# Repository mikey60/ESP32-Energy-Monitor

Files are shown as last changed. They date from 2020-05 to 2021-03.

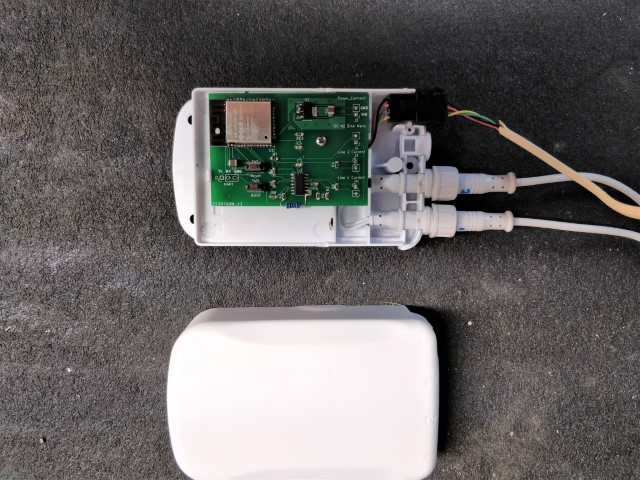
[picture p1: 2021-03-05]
Images/Energy_monitor_1 (Small).jpg

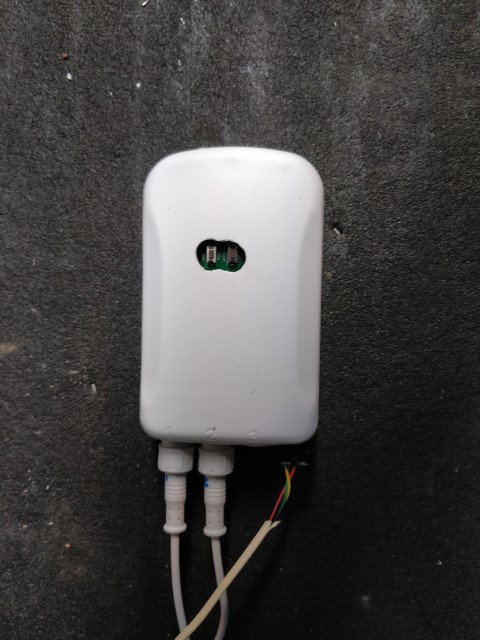
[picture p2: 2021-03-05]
Images/Energy_monitor_2 (Small).jpg

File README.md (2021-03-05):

# ESP32-Energy-Monitor
Hardware and code are designed to use the Aeon labs Home Energy Meter, model DSB09104-zwus, current clamps and housing.  I was frustrated with the occasional intermittent connection of the Aeon Labs Home Energy meter because the Z-Wave hub and energy meter were two floors apart.  Also the energy meter would occasionally give very high erroneous readings.  The unit did not work at all after I upgraded the firmware. That is what led to the ESP32 energy monitor project.

**Features:**
* Uses Aeon labs DSB09104-zwus current clamps and housing
* Wifi has increased signal strength over Z-Wave
* Uses a minimum amount of components
* Calculates real power like residential energy meters
* The capability of calculating power factor could be added
* Can easily adjust the scale factors to get agreement with energy company's meter
* Can debug using WiFi and telnet
* Can download new code Over The Air (OTA)

**Disadvantages:**
* The power supply is old school with a 60Hz transformer with a diode bridge and 1000uF capacitor to provide the DC power and the 60 Hz AC signal to the energy meter.  I picked up the 6 volt DC, 800mA class 2 power supply at the local surplus store.  I opened the power supply to add the two wires for the sine wave input to the energy monitor.  I also added two 1 amp rectifier diodes in series with the filtered DC output to the reduce the power of the AMS1117-3.3 LDO regulator on the energy monitor board.
* There is some distortion of the sine wave voltage due to the load on the power supply.
* The output of the current clamps is also distorted especially at low currents. The linearity of the output versus power is not too bad even with the distortion.
* The WiFi activity adds some noise to  the A/D coversions.
* The energy totals get reset if there is a wifi problem or power interruption. Additonal code could be written to keep a running sum in Flash every so often.

**PCB**

The KiCad PCB files can be found in the PCB folder including a PDF file of the schematic and layout.
There are two modifications that I made to the hardware design that are not shown in the documentation of the PCB folder.

Modifications
* I added a 22uF capacitor directly across the output and ground pins of the AMS1117-3.3 LDO regulator to stop the output oscillation.  The other 22uF capacitor on the 3.3 volt output of the LDO regulator is close to the ESP32. 
* I addded a 200pF capacitor and a 100 ohm resistor to the op amp circuit that provides the 3.3/2 volt virtual ground to provide stability when driving a capacitive load.  The output would oscillate when a 1x probe (120pF capacitance) was touched to the output.  The Micro-Cap 12 stability analysis showed that the circuit should be stable with a 120pF capacitor.  See 'Stability Analysis' in the data folder. Maybe there is other capacitances I am not accounting for or maybe the LMC6484 op amp I purchased on ebay is deficient in the stability performance area.  The Micro-Cap file is also in the data folder.  By the way, the Micro-cap 12 simulator is now free. 

**Other Information**

* Pictures of the finished device can be found in the images folder.
* A plot of the current consumption of the device can be found in the data folder.
* I attached a logic analyzer  to pin IO4 and let it run for an hour and did not see any missed 1 KHz samples

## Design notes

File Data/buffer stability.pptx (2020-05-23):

## LM6484 Stability Analysis

120pf 1X scope probe load

## Virtual Ground Amplifier Stability as Designed

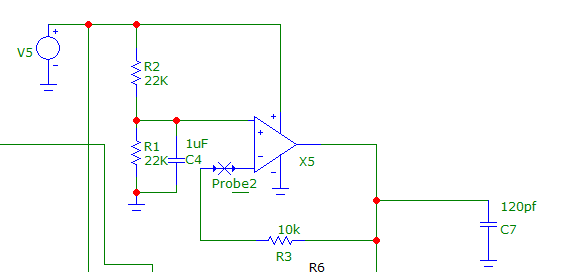
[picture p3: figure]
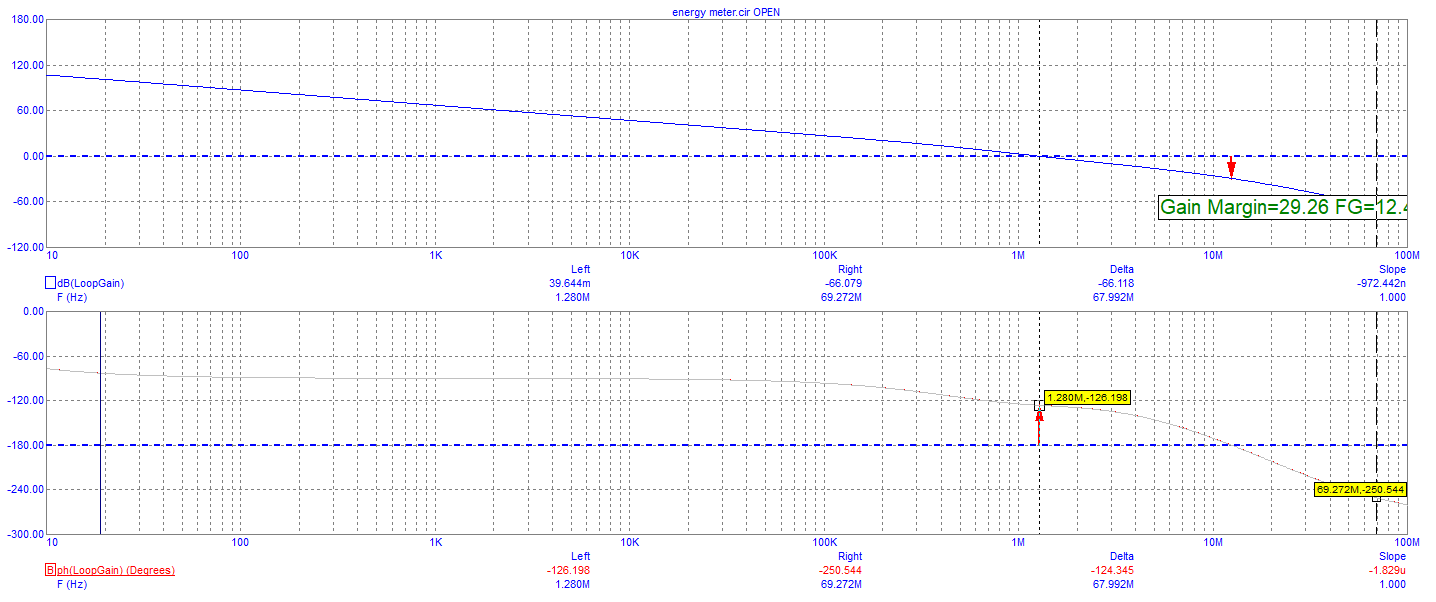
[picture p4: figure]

Phase Margin = 53.78°

## Virtual Ground Amplifier Stability with Capacitive Load Capability

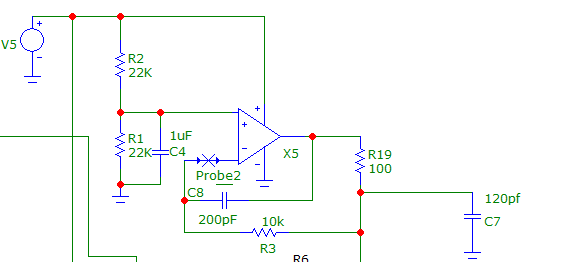
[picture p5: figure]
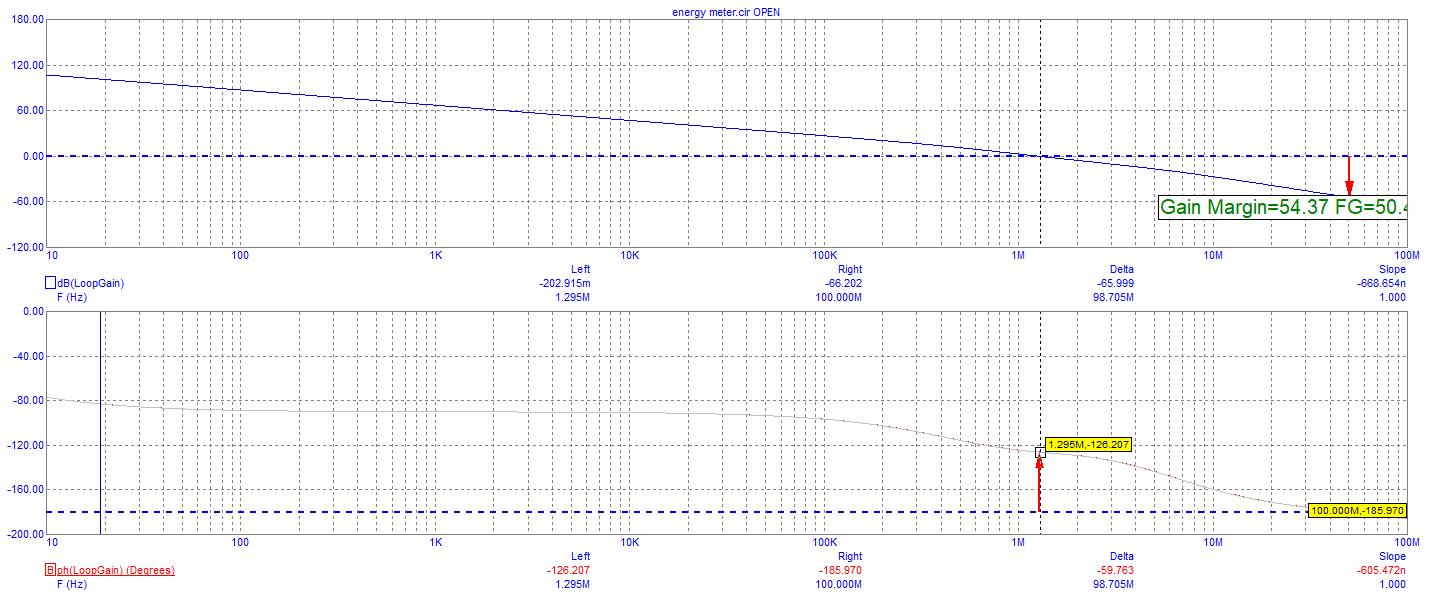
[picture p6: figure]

Phase Margin = 53.9°

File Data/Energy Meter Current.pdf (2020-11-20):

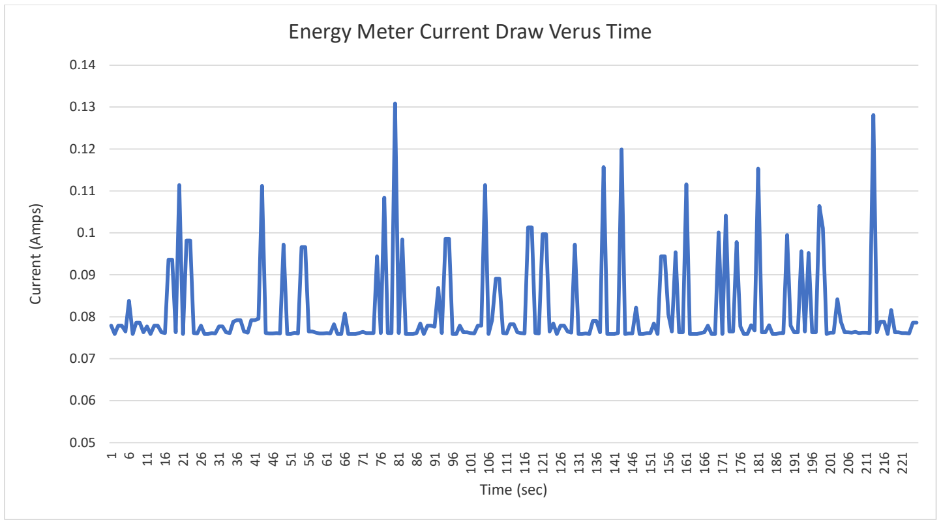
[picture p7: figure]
Time (sec); Energy Meter Current Draw Verus Time

6111621263136414651566166717681869196 101 106 111 116 121 126 131 136 141 146 151 156 161 166 171 176 181 186 191 196 201 206 211 216 221 Current (Amps)

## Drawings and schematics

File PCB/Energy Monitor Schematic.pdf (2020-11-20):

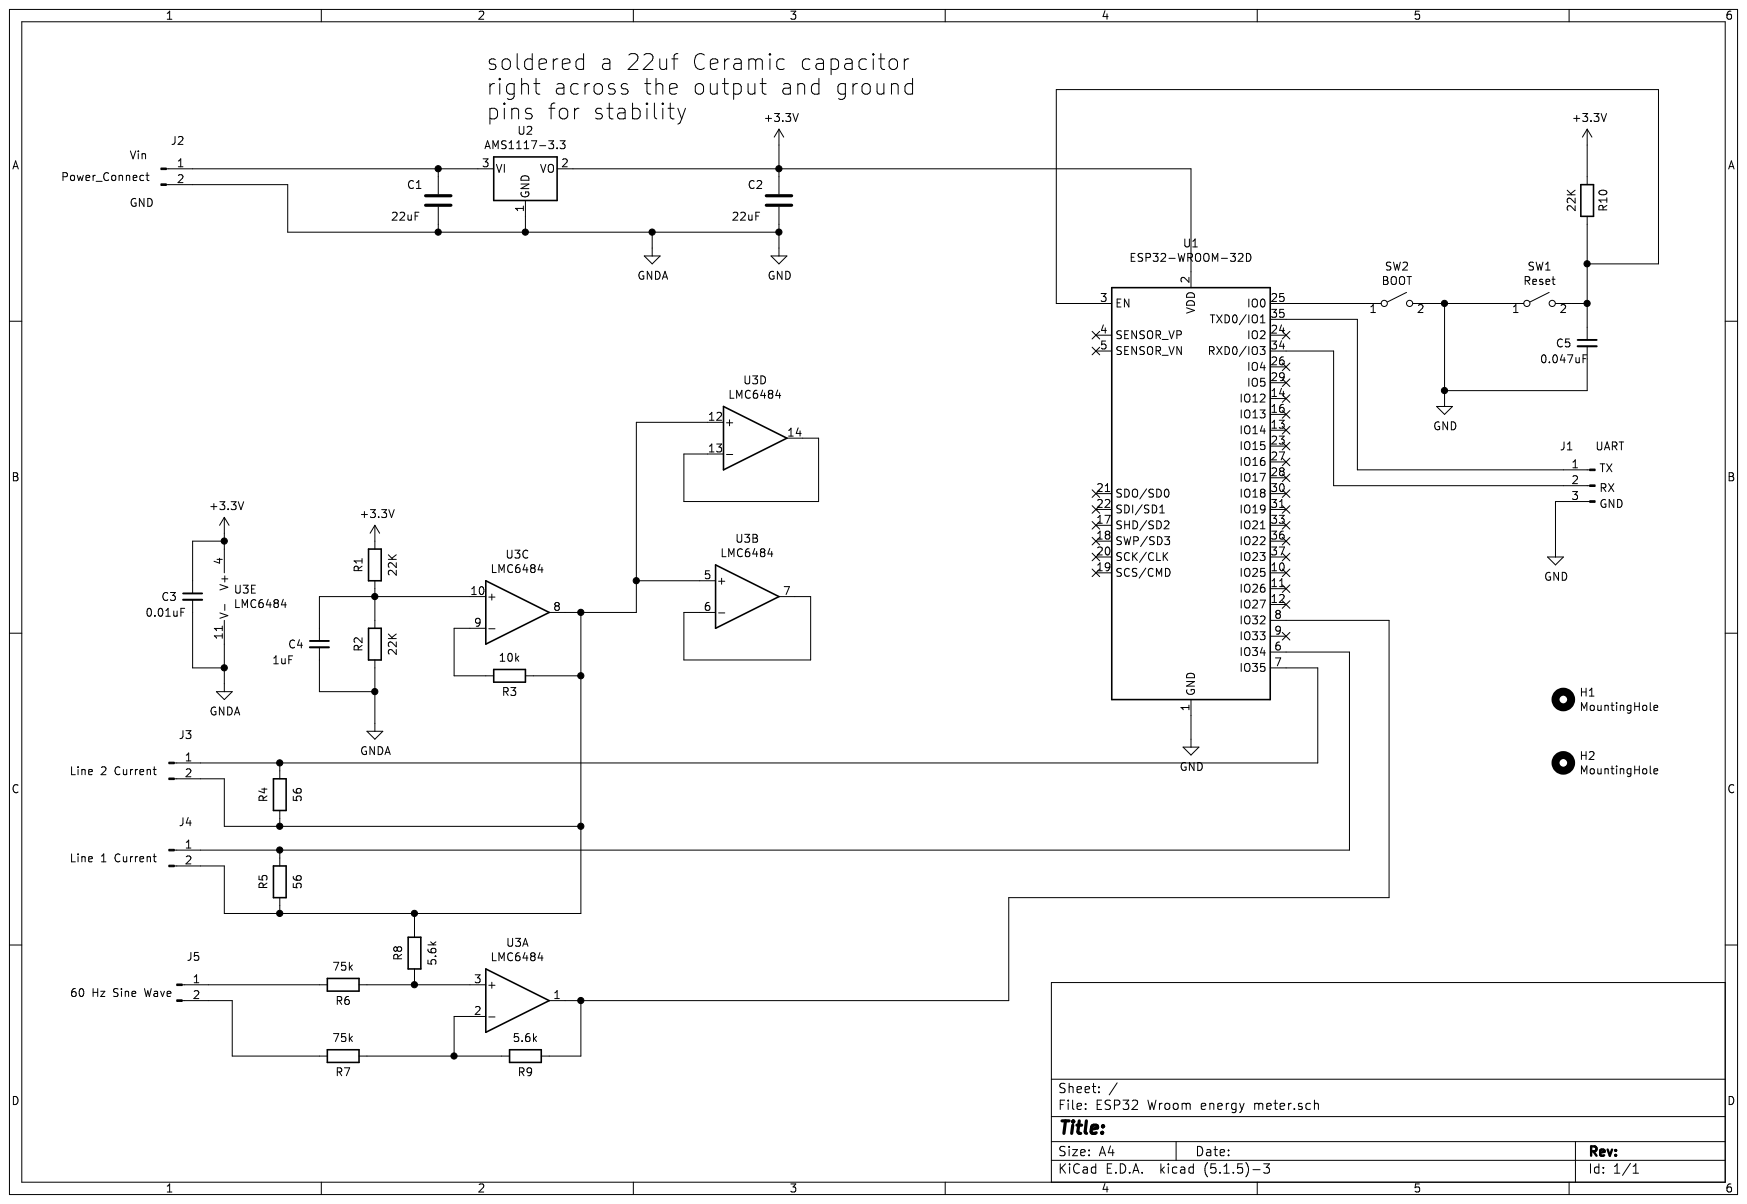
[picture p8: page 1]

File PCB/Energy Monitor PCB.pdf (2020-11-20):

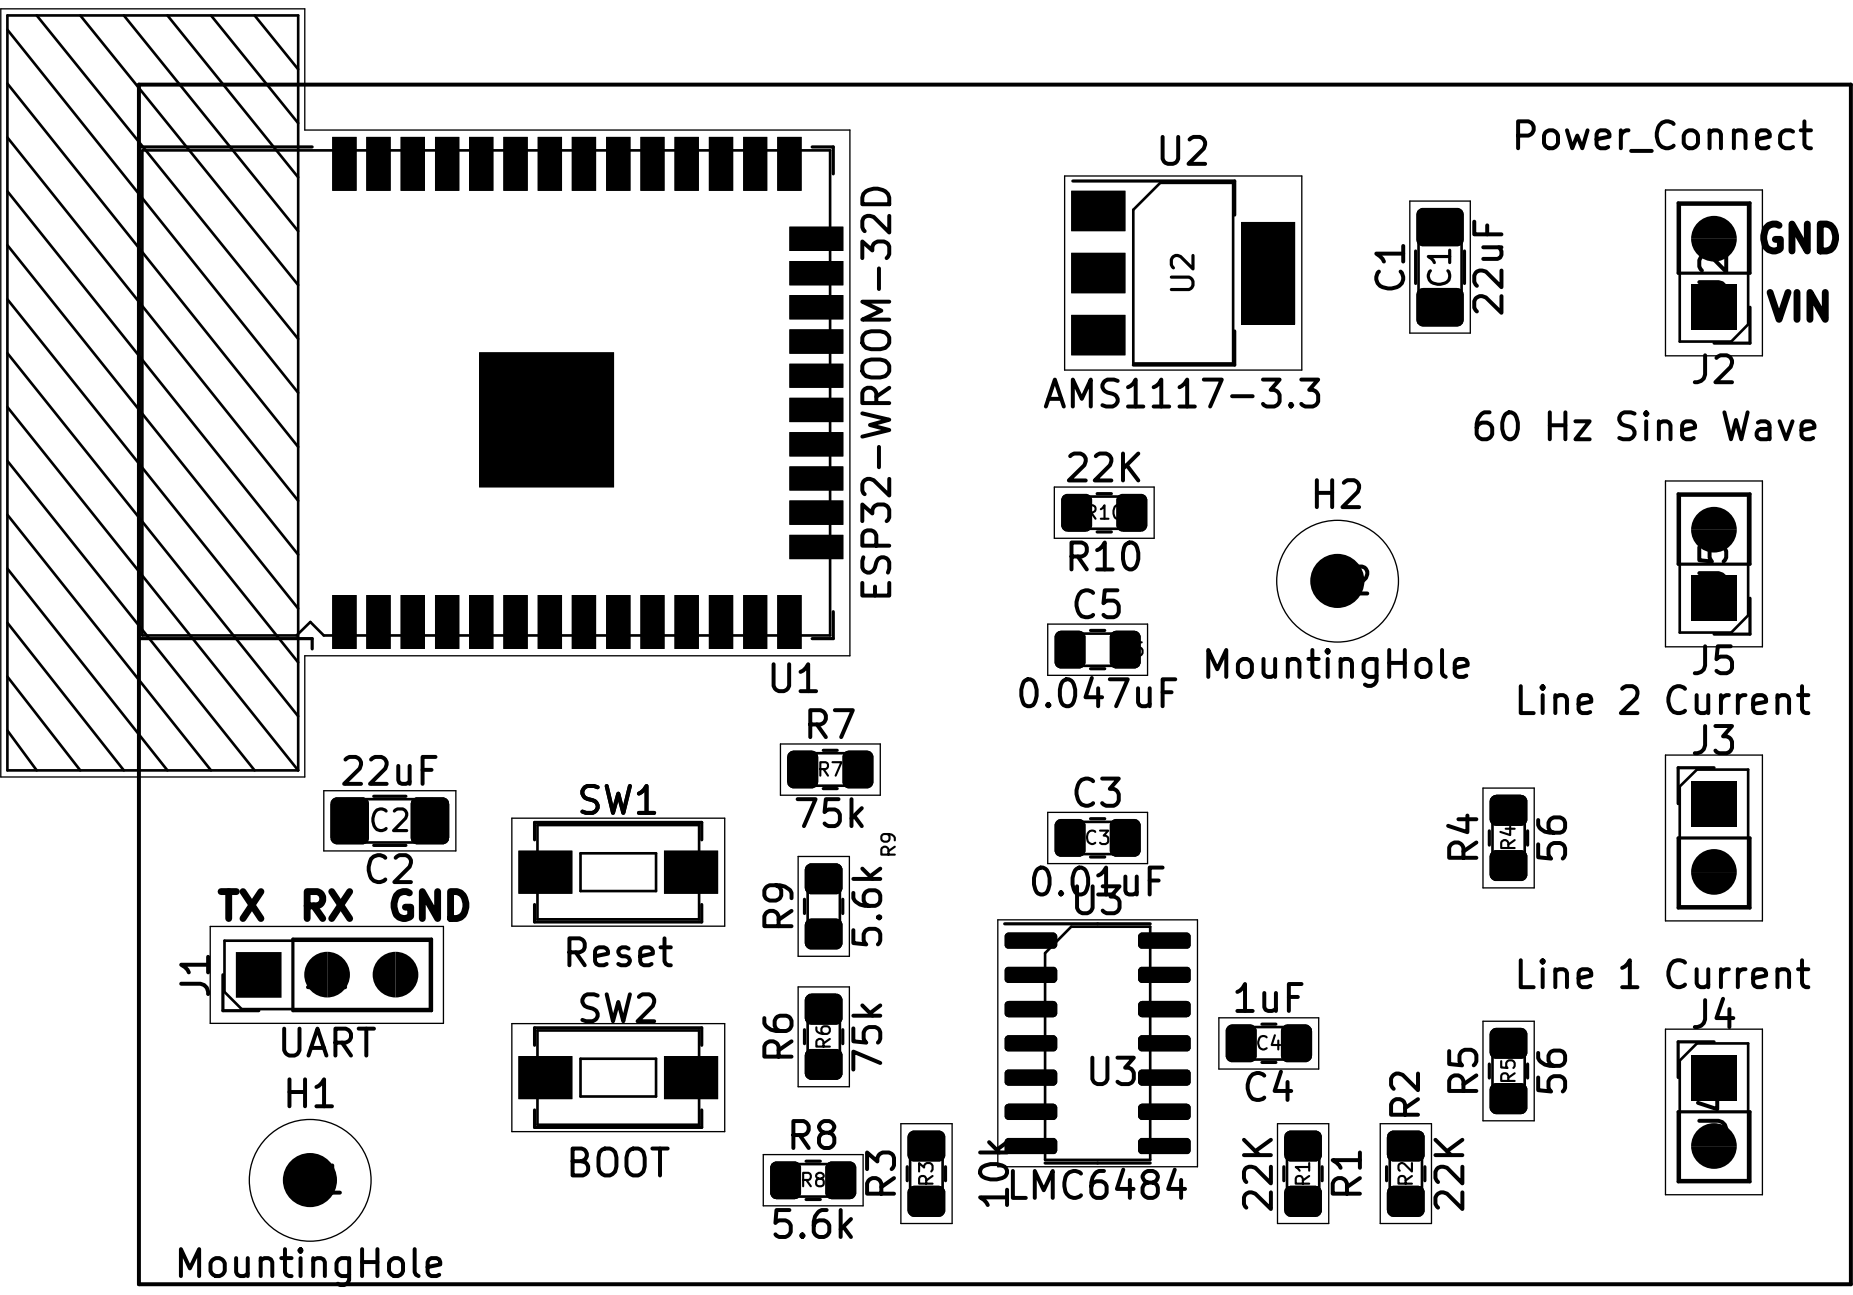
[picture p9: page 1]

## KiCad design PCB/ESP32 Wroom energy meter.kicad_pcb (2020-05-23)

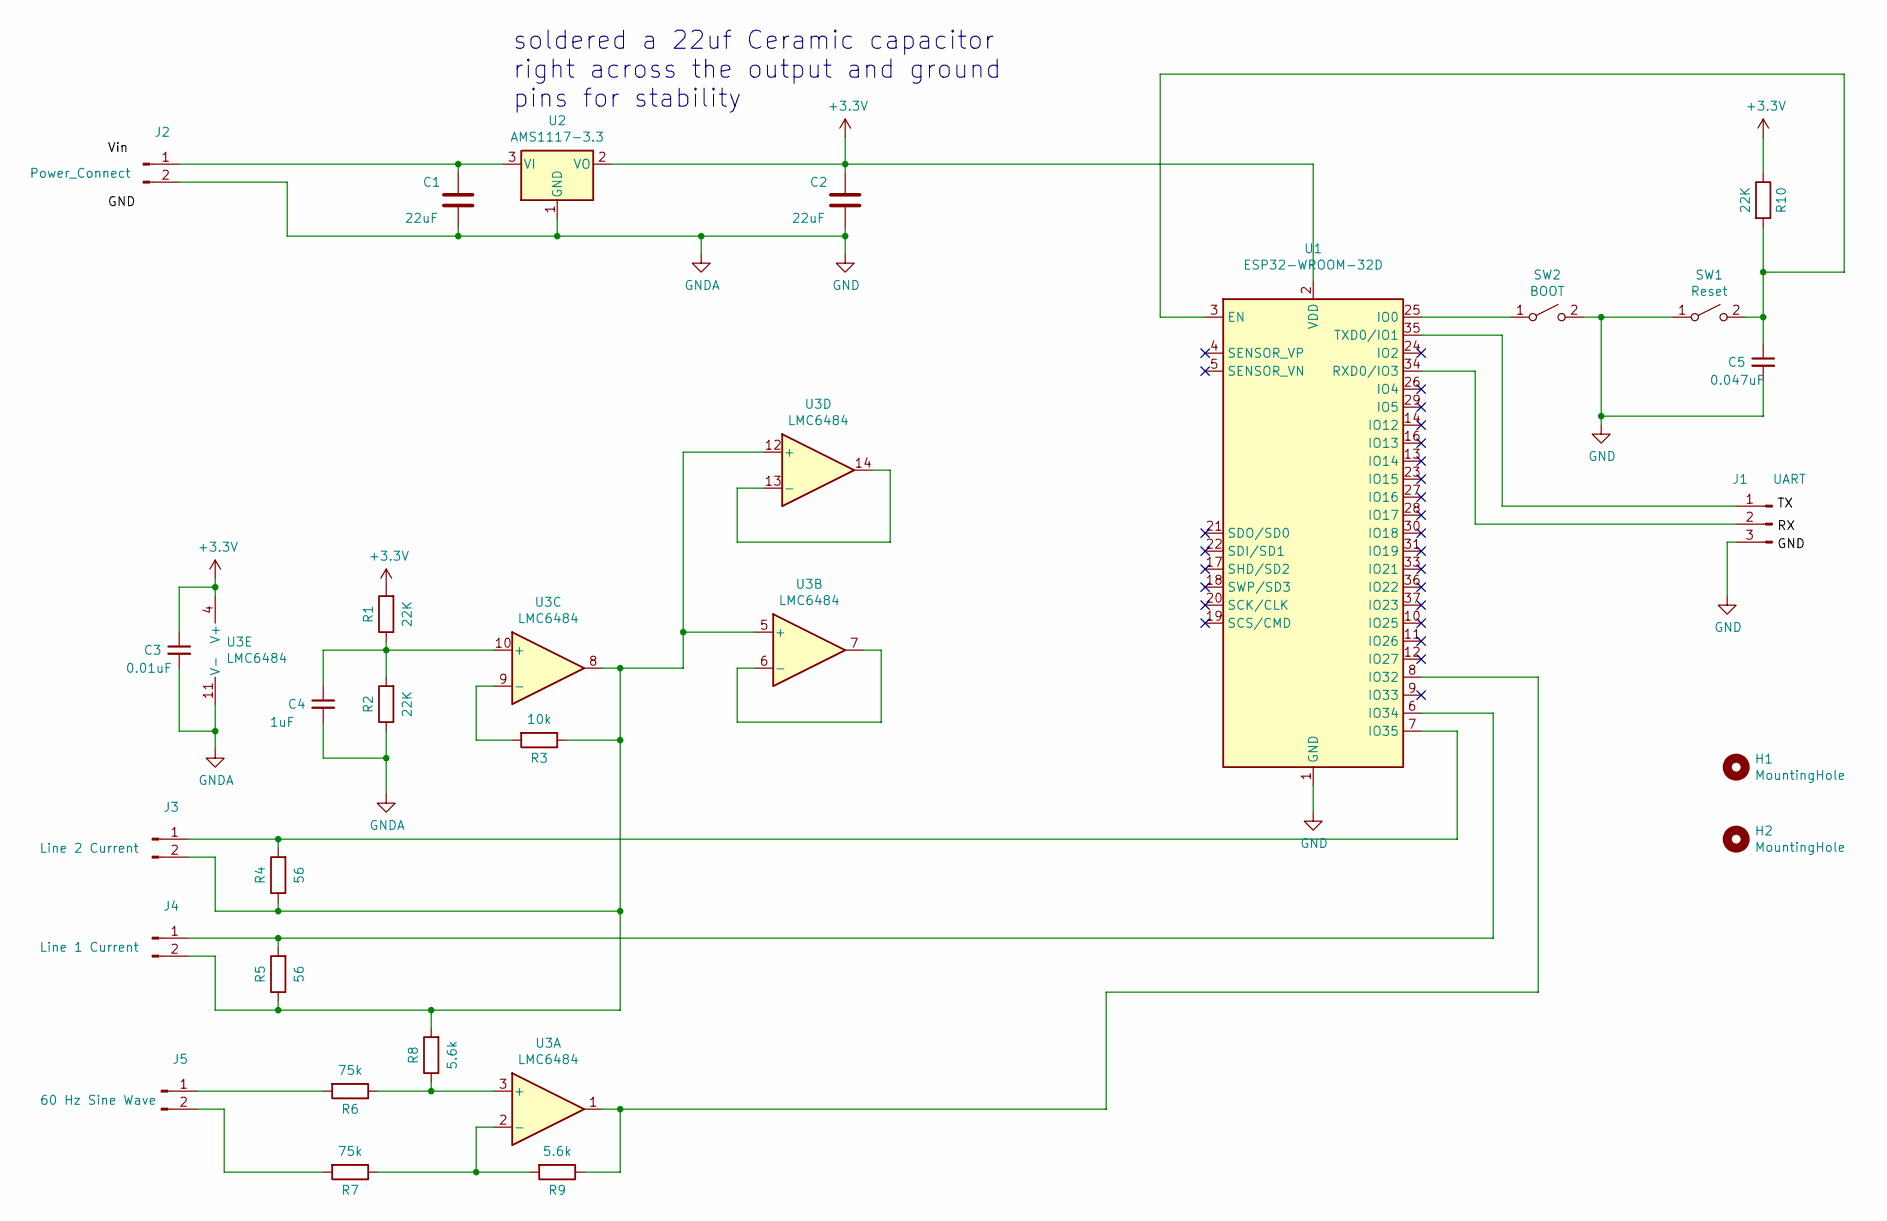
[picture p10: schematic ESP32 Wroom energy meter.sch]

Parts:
C1, C2: 22uF; C_1206_3216Metric_Pad1.42x1.75mm_HandSolder
C3: 0.01uF; C_0805_2012Metric_Pad1.15x1.40mm_HandSolder
C4: 1uF; C_0805_2012Metric_Pad1.15x1.40mm_HandSolder
C5: 0.047uF; C_0805_2012Metric_Pad1.15x1.40mm_HandSolder
H1, H2: MountingHole; MountingHole_2mm
J1: UART; PinHeader_1x03_P2.54mm_Vertical
J2: Power_Connect; PinHeader_1x02_P2.54mm_Vertical
J3: Line 2 Current; PinHeader_1x02_P2.54mm_Vertical
J4: Line 1 Current; PinHeader_1x02_P2.54mm_Vertical
J5: 60 Hz Sine Wave; PinHeader_1x02_P2.54mm_Vertical
R1, R2, R10: 22K; R_0805_2012Metric_Pad1.15x1.40mm_HandSolder
R3: 10k; R_0805_2012Metric_Pad1.15x1.40mm_HandSolder
R4, R5: 56; R_0805_2012Metric_Pad1.15x1.40mm_HandSolder
R6, R7: 75k; R_0805_2012Metric_Pad1.15x1.40mm_HandSolder
R8, R9: 5.6k; R_0805_2012Metric_Pad1.15x1.40mm_HandSolder
SW1: Reset; SW_SPST_EVQPE1
SW2: BOOT; SW_SPST_EVQPE1
U1: ESP32-WROOM-32D; ESP32-WROOM-32
U2: AMS1117-3.3; SOT-223-3_TabPin2
U3: LMC6484; SOIC-14_3.9x8.7mm_P1.27mm

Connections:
+3V3: C2.1, C3.1, R1.2, R10.1, U1.2 (VDD), U2.2 (VO), U3.4 (V+)
GND: C1.2, C2.2, C3.2, C4.2, C5.2, J1.3, J2.2, R2.1, SW1.1 (A), SW2.2 (B), U1.1 (GND), U1.15 (GND), U1.38 (GND), U1.39 (GND), U2.1 (GND), U3.11 (V-)
unnamed: C1.1, J2.1, U2.3 (VI)
unnamed: C4.1, R1.1, R2.2, U3.10 (+)
unnamed: C5.1, R10.2, SW1.2 (B), U1.3 (EN)
unnamed: J1.1, U1.35 (TXD0/IO1)
unnamed: J1.2, U1.34 (RXD0/IO3)
unnamed: J3.1, R4.2, U1.7 (IO35)
unnamed: J3.2, J4.2, R3.1, R4.1, R5.1, R8.2, U3.5 (+), U3.8, U3.12 (+)
unnamed: J4.1, R5.2, U1.6 (IO34)
unnamed: J5.1, R6.2
unnamed: J5.2, R7.2
unnamed: R3.2, U3.9 (-)
unnamed: R6.1, R8.1, U3.3 (+)
unnamed: R7.1, R9.2, U3.2 (-)
unnamed: R9.1, U1.8 (IO32), U3.1
unnamed: SW2.1 (A), U1.25 (IO0)
unnamed: U3.6 (-), U3.7
unnamed: U3.13 (-), U3.14

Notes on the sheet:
soldered a 22uf Ceramic capacitor right across the output and ground pins for stability

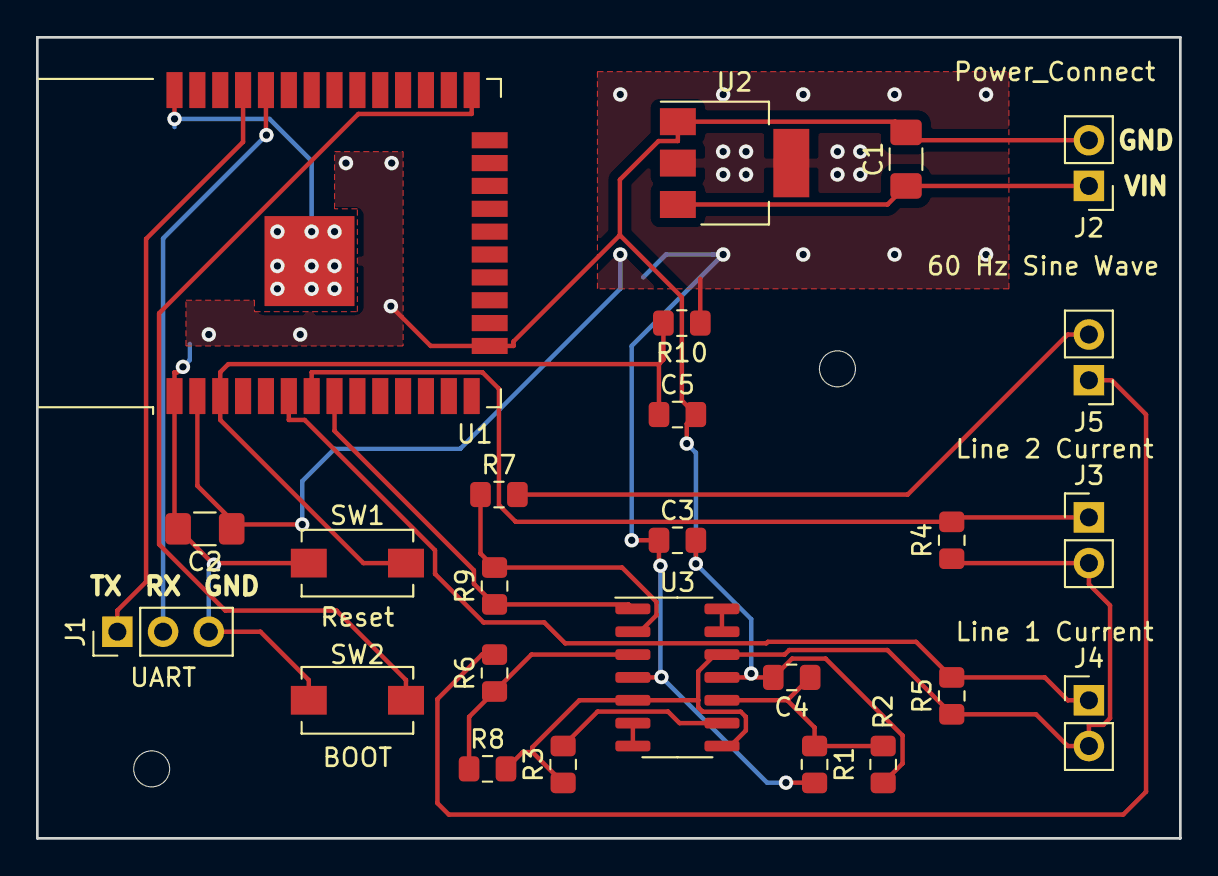
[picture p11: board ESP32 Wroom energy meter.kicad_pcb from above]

Board: 2 copper layers, 63.5 x 44.5 mm, 27 parts (0 on the bottom side), 19 nets.

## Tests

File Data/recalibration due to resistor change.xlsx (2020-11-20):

Meter reading | Delta | ESP32 reading | Delta | Ratio
2352.5 |  | 0.19
2413.5 | 61 | 66.03 | 65.84 | 0.9264884569
2677 | 263.5 | 350.85 | 284.82 | 0.9251457061
2744.7 | 67.7 | 424.04 | 73.19 | 0.9249897527
 |  |  |  | 0.9255413052 | = average correction factor

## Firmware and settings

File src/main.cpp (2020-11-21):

/***************************************************************************
 MQTT Energy Monitor uses Aeon labs DSB09104-zwus current clamps and housing 
****************************************************************************/ 
#include <WiFi.h>
#include <PubSubClient.h>
#include <ArduinoOTA.h>
#include "esp_wifi.h"

//#define DEBUG_SERIAL
#define DEBUG_TELNET

#if defined(DEBUG_TELNET)
#define DEBUG_TELNET_PORT 23
#endif

#if defined(DEBUG_TELNET)
WiFiServer  telnetServer(DEBUG_TELNET_PORT);
WiFiClient  telnetClient;
#define     DEBUG_PRINT(x)    telnetClient.print(x)
#define     DEBUG_PRINTLN(x)  telnetClient.println(x)

#elif defined(DEBUG_SERIAL)
#define     DEBUG_PRINT(x)    Serial.print(x)
#define     DEBUG_PRINTLN(x)  Serial.println(x)
#else
#define     DEBUG_PRINT(x)
#define     DEBUG_PRINTLN(x)
#endif

#if CONFIG_FREERTOS_UNICORE
#define ARDUINO_RUNNING_CORE 0
#else
#define ARDUINO_RUNNING_CORE 1
#endif

#ifndef LED_BUILTIN
#define LED_BUILTIN 13
#endif
#define portTICK_PERIOD_MS 1

#define OTA_password "your_OTA_password"
const char* ssid = "your_SSID";
const char* password = "your_SSID_password";
const char* hostname = "Energy Monitor";
const char* mqttServer = "xxx.xxx.xxx.xxx"; //your IP address
const int mqttPort = 1883;
//const char* mqttUser = "yourMQTTuser";   //Use if desired
//const char* mqttPassword = "yourMQTTpassword";

WiFiClient espClient;
PubSubClient client(espClient);

//counters to limit connection retries
volatile int wifi_cnt = 0;
volatile int mqtt_cnt = 0;


const int line1_current = 34; //pin for line 1 current ADC input
const int line2_current = 35; //pin for line 2 current ADC input
const int voltage = 32;  //pin for voltage ADC input
//const int Pin_DC_bias = 25;  // pin to provide dc bias to AC current ADC samples 
const int Pin_time = 4; // pin to check sampling time
const int nsamples = 1000;
const unsigned long time_between_messages = 300000UL; // Time in msec
const double power_change = 200.0;  //The power change threshold to send MQTT message
const double fsamples = 1000.0;
const double twoPI = 6.2831853;
//const int DC_bias = 127; // 255 is full scale ~3.3 volts not using in design using resitor divider
const double SF_line1 = 0.00934755; //  
const double SF_line2 = 0.00934755; // Scale factors determined by calibrating against power meter
volatile int buff_cnt = 0;
volatile int buff1 = true;  // Buffer indicator: true = buff1 and false = buff2 
volatile double line1_buff1[nsamples];
volatile double line1_buff2[nsamples];
volatile double line2_buff1[nsamples];
volatile double line2_buff2[nsamples];
volatile double v_buff1[nsamples];
volatile double v_buff2[nsamples];
volatile bool buff1_full = false;
volatile bool buff2_full = false;
volatile double line1_energy = 0.0;
volatile double line2_energy = 0.0;
volatile double total_energy = 0.0;
volatile double line1_avg_pwr;
volatile double line2_avg_pwr;
volatile double total_power;
volatile double line1_energy_buff = 0.0;
volatile double line2_energy_buff = 0.0;
volatile double total_energy_buff = 0.0;
volatile double line1_avg_pwr_buff = 0.0;
volatile double line2_avg_pwr_buff = 0.0;
volatile double total_power_buff = 0.0;
volatile double value[6];
volatile bool MQTT_message_flag = false;
volatile long last_time = 0L;
String line1_avg_pwr_topic = "sensor/clamp1_power";
String line2_avg_pwr_topic = "sensor/clamp2_power";
String total_power_topic = "sensor/total_power";
String line1_energy_topic = "sensor/clamp1_energy";
String line2_energy_topic = "sensor/clamp2_energy";
String total_energy_topic = "sensor/total_energy";
String topic0 = "sensor/clamp1_power";
String topic1 = "sensor/clamp2_power";
String topic2 = "sensor/total_power";
String topic3 = "sensor/clamp1_energy";
String topic4 = "sensor/clamp2_energy";
String topic5 = "sensor/total_energy";
TaskHandle_t Sc;
TaskHandle_t Cap;
TaskHandle_t Sp;

long strt = 0L;
// Set Static IP address
IPAddress local_IP(192, 168, 1, 41);
// Set Gateway  and subnet
IPAddress gateway(192, 168, 1, 1);
IPAddress subnet(255, 255, 0, 0);


/***          Function Prototypes        ****/
void handleTelnet(void);
double multiple_adc_read(int pinnum);
void Sample_current( void *pvParameters );
void Calculate_avg_power( void *pvParameters );
void Send_power(void *pvParameters);
void callback(char* topic, byte* payload, unsigned int length);
/*
   Function called to handle Telnet clients
   https://www.youtube.com/watch?v=j9yW10OcahI
*/
#if defined(DEBUG_TELNET)
void handleTelnet(void) {
  if (telnetServer.hasClient()) {
    if (!telnetClient || !telnetClient.connected()) {
      if (telnetClient) {
        telnetClient.stop();
      }
      telnetClient = telnetServer.available();
    } else {
      telnetServer.available().stop();
    }
  }
}
#endif

void callback(char* topic, byte* payload, unsigned int length) {
  Serial.print("Message arrived [");
  Serial.print(topic);
  Serial.print("] ");
  for (int i=0;i<length;i++) {
    Serial.print((char)payload[i]);
  }
  Serial.println();
}


/*--------------------------------------------------*/
/*---------------------- Tasks ---------------------*/
/*--------------------------------------------------*/

void Send_power(void *pvParameters)  // This is a task.
// This is a task to send the power and energy data to Home-Assistant MQTT server when flag is set.
{
  (void) pvParameters;
  String topic;
 for (;;) // A Task that never returns or exits.
  {
    vTaskDelay(1);
    ArduinoOTA.handle();
    #if defined(DEBUG_TELNET)
    // handle the Telnet connection
     handleTelnet();
    #endif
    strt=xTaskGetTickCount();
    if(MQTT_message_flag == true)  //Only send data when true
    {
      mqtt_cnt = 0;    
        while (!client.connected() &&  mqtt_cnt <6)
        { 
      
          DEBUG_PRINTLN("Connecting to MQTT...");
          if (client.connect("ESP32Power")) 
          {
            DEBUG_PRINTLN("connected to MQTT server");
            //DEBUG_PRINTLN("line1_avg_pwr string = " + String(line1_avg_pwr_buff));
            client.subscribe(line1_avg_pwr_topic.c_str());
            client.publish(line1_avg_pwr_topic.c_str(), String(line1_avg_pwr_buff).c_str(), true);
            client.publish(line2_avg_pwr_topic.c_str(), String(line2_avg_pwr_buff).c_str(), true);
            client.publish(total_power_topic.c_str(), String(total_power_buff).c_str(), true);
            client.publish(line1_energy_topic.c_str(), String(line1_energy_buff).c_str(), true);
            client.publish(line2_energy_topic.c_str(), String(line2_energy_buff).c_str(), true);
            client.publish(total_energy_topic.c_str(), String(total_energy_buff).c_str(), true);
            client.subscribe(total_energy_topic.c_str());

          } 
          else 
          {
            DEBUG_PRINT("failed with state ");
            DEBUG_PRINTLN(client.state());
            delay(1000);
            mqtt_cnt ++;  // only allow 6 trys for connection to MQTT server
          }
          if(mqtt_cnt >= 6) esp_restart(); // restart the device at this point
          // Todo: Save line 1, line 2 and total energy other wise they are reset to 0
          // Possibly could just call WiFi.mode(WIFI_OFF) and WiFi.begin(...) 
  
         }
      client.disconnect();
      //WiFi.disconnect();    
      //WiFi.mode(WIFI_OFF);
      MQTT_message_flag = false;  //reset flag
      //DEBUG_PRINTLN(xTaskGetTickCount());
        DEBUG_PRINTLN(ESP.getFreeHeap());
      //DEBUG_PRINTLN("Reset MQTT flag");
      //vTaskResume(Sc);
      //vTaskResume(Cap);

    }
  }
}

void Calculate_avg_power(void *pvParameters)  // This is a task.
// This is a task to calculate average power (real power) once a second from sampled current ADC Buffer.
{
  (void) pvParameters;
  int jj;
  int kk = 0;
  double sum_line1 = 0.0;
  double sum_line2 = 0.0;
  double sum_v = 0.0;
  double DC_offset1, DC_offset2, DC_offsetv;
  double sum_line1_pwr = 0.0; 
  double sum_line2_pwr = 0.0;
  volatile double total_power_p;   //Power from last measurement
  //volatile long last_time = 0L;  //Time of last MQTT message

  /*
  Calculates power and energy once a second of line current and voltage of ADC buffer*/


  for (;;) // A Task that never returns or exits.
  {
    vTaskDelay(1);
    if(buff1_full || buff2_full)
    {

      for(jj = 0; jj < nsamples; jj++)
      {
        if(buff1_full)
        {
          //DEBUG_PRINTLN(line1_buff1[jj]);
          sum_line1 += line1_buff1[jj];
          sum_line2 += line2_buff1[jj];
          sum_v += v_buff1[jj];
        }
        else
        {
          sum_line1 += line1_buff2[jj];
          sum_line2 += line2_buff2[jj];
          sum_v += v_buff2[jj];
        }
      }
      DC_offset1 = sum_line1/fsamples;
      DC_offset2 = sum_line2/fsamples;
      DC_offsetv = sum_v/fsamples;
      //DEBUG_PRINT("DC=");  DEBUG_PRINTLN(DC_offset1);
     for(jj = 0; jj < nsamples; jj++)
     {
       if(buff1_full)
       {
          sum_line1_pwr += (line1_buff1[jj] - DC_offset1) * (v_buff1[jj] - DC_offsetv);
          sum_line2_pwr += (line2_buff1[jj] - DC_offset2) * (v_buff1[jj] - DC_offsetv);       
       }
       else
       {
          sum_line1_pwr += (line1_buff2[jj] - DC_offset1) * (v_buff2[jj] - DC_offsetv);
          sum_line2_pwr += (line2_buff2[jj] - DC_offset2) * (v_buff2[jj] - DC_offsetv);
       }
      }
      //DEBUG_PRINT("buff1=");  DEBUG_PRINTLN(buff1);
      //line1_rms_current = sqrt(sum_line1_sqr/fsamples); 
      //line2_rms_current = sqrt(sum_line2_sqr/fsamples);

      // Take the absolute value of the power because on the the line currents
      // is out of phase with the voltage just in case this is not taken care
      // in the output connection of the current clamp.
      line1_avg_pwr = abs(sum_line1_pwr/fsamples) * SF_line1;
      line2_avg_pwr = abs(sum_line2_pwr/fsamples) * SF_line2;
      /* 
      delay(5);    
      DEBUG_PRINT(kk);  DEBUG_PRINT(":1:");  DEBUG_PRINTLN(line1_avg_pwr); 
      DEBUG_PRINT(kk);  DEBUG_PRINT(":2:");  DEBUG_PRINTLN(line2_avg_pwr);    
      delay(5);
      */
      total_power_p = total_power; //Save previous total power reading
      total_power = line1_avg_pwr + line2_avg_pwr;
      //output one second power for data noise analysis
      //DEBUG_PRINTLN(total_power);
      line1_energy += line1_avg_pwr/3600.0/1000.0;  // kWh  
      line2_energy += line2_avg_pwr/3600.0/1000.0;  // kWh
      total_energy = line1_energy + line2_energy; // kWh 
      // zero out sums for next pass
      sum_line1 = 0.0;
      sum_line2 = 0.0;
      sum_v = 0.0;
      sum_line1_pwr = 0.0; 
      sum_line2_pwr = 0.0;
      // Flag buffer full as false because data of buffer has been calculated
      if(!buff1)
      {
        buff1_full = false;
        kk++;
      }
      else
      {
        buff2_full = false;
        kk++;
      }
      // Check for significant power change or 5 minutes since last message to 
      // set Flag to send measurements message to Home-Assistant MQTT server
      if((xTaskGetTickCount()-last_time > time_between_messages) || abs(total_power-total_power_p) > power_change )
      {
        line1_energy_buff = line1_energy;
        line2_energy_buff = line2_energy;
        total_energy_buff = total_energy;
        line1_avg_pwr_buff = line1_avg_pwr;
        line2_avg_pwr_buff = line2_avg_pwr;
        total_power_buff = total_power;
        /*line1_energy_buff++;
        line2_energy_buff++;
        total_energy_buff++;
        line1_avg_pwr_buff++;
        line2_avg_pwr_buff++;
        total_power_buff++;*/
        //for(int q=0; q<6; q++)
        //{
         // value[q]++;
        //}
        MQTT_message_flag = true;
        last_time = xTaskGetTickCount();
        //vTaskSuspend(Sc);
        //vTaskSuspend(Cap);

      }  
    }
  }
}

void Sample_current(void *pvParameters)  // This is a task.
{
  (void) pvParameters;
  
/*
Read current of both lines and voltage
*/
  TickType_t xLastWakeTime;
  const TickType_t xFrequency = 1;
  // Initialise the xLastWakeTime variable with the current time.
  xLastWakeTime = xTaskGetTickCount();
  //DEBUG_PRINTLN("got to here2");
  for (;;) // A Task that never returns or exits.
  {
    // Wait for the next cycle.
    vTaskDelayUntil( &xLastWakeTime, xFrequency );
    digitalWrite(Pin_time, HIGH);
    //  DEBUG_PRINT(".");
        if( buff_cnt < nsamples && buff1)
    {  
      noInterrupts();
      line1_buff1 [buff_cnt] = multiple_adc_read(line1_current);
      line2_buff1 [buff_cnt] = multiple_adc_read(line2_current);
      v_buff1 [buff_cnt] = multiple_adc_read(voltage);
      //v_buff1 [buff_cnt] = 200.0*sin(twoPI * 60.0 * double(buff_cnt)/fsamples) +  multiple_adc_read(voltage);
      interrupts();
      //DEBUG_PRINTLN(".");
    }
    else if( buff_cnt < nsamples && !buff1)
    {
      noInterrupts();
      line1_buff2 [buff_cnt] = multiple_adc_read(line1_current);
      line2_buff2 [buff_cnt] = multiple_adc_read(line2_current);  
      v_buff2 [buff_cnt] = multiple_adc_read(voltage);
      //v_buff2 [buff_cnt] = 200.0*sin(twoPI * 60.0 * double(buff_cnt)/fsamples) +  multiple_adc_read(voltage);
      interrupts();
      //DEBUG_PRINTLN("-");
  
    }
    buff_cnt++;  // Increment data index
    if(buff_cnt == nsamples)
    {
      if(buff1)
      {
        buff1_full = true;
        //DEBUG_PRINTLN(buff1_full);
        //buff2_full = false;  // Extra insurance
        buff_cnt = 0;
        buff1 = false;  // Switch to buffer 2
      } 
      else
      {
        buff2_full = true;
        //buff1_full = false;  // Extra insurance
        buff_cnt = 0;
        buff1 = true;  // Switch to buffer 1    
      }
    }
  digitalWrite(Pin_time, LOW);  
  } 
}

// the setup function runs once when you press reset or power the board
void setup() {
  // initialize serial communication at 115200 bits per second:
  Serial.begin(115200);
  delay(10);
  // ****  Start and connect to WiFi network **** //
  WiFi.mode(WIFI_STA);
  WiFi.setHostname(hostname);
  WiFi.config(local_IP, gateway, subnet);
  WiFi.begin(ssid, password);
  while (WiFi.status() != WL_CONNECTED && wifi_cnt < 6) {
    delay(1000);
    wifi_cnt ++;  
    DEBUG_PRINTLN("Connecting to WiFi..");
  }
  if(wifi_cnt < 6){  //only allow about 4 seconds for connection to wifi router
    DEBUG_PRINTLN("Connected to the WiFi network");
    DEBUG_PRINT("IP address: ");  DEBUG_PRINTLN(WiFi.localIP());
  }   
  else{
    DEBUG_PRINTLN(" NOT connected to the WiFi network");  
  }
 
  client.setServer(mqttServer, mqttPort);
  client.setCallback(callback);

  pinMode(line1_current, INPUT);
  pinMode(line2_current, INPUT);
  //pinMode(Pin_DC_bias, OUTPUT);
  pinMode(Pin_time, OUTPUT);
  //dacWrite(Pin_DC_bias, DC_bias);
  DEBUG_PRINTLN("got to here");

 #if defined(DEBUG_SERIAL)
//    Serial.begin(115200); //already started
  #elif defined(DEBUG_TELNET)
    telnetServer.begin();
    telnetServer.setNoDelay(true);
  #endif


  // Setup OTA
  #if defined(OTA_password)
    ArduinoOTA.setPassword((const char *)OTA_password);
  #endif
    DEBUG_PRINTLN(String("Hostname: ") + hostname);
    ArduinoOTA.setHostname(hostname);
  //  ArduinoOTA.onProgress(drawOtaProgress);
  ArduinoOTA.begin();
  
  //esp_wifi_set_max_tx_power(127);   

  // Now set up three tasks to run independently.
  xTaskCreatePinnedToCore(
    Sample_current
    ,  "Sample_current"
    ,  2048  // Stack size
    ,  NULL
    ,  6  // Priority
    ,  &Sc // Task Handle
    ,  1);  //Run on Core 1 for best sampling?
  xTaskCreatePinnedToCore(
    Calculate_avg_power
    ,  "Calculate_avg_power"   // A name just for humans
    ,  8192  // This stack size can be checked & adjusted by reading the Stack Highwater
    ,  NULL
    ,  4  // Priority of 2 (configMAX_PRIORITIES - 1) being the highest, and 0 being the lowest.
    ,  &Cap //Task Handle
    ,  0);
  xTaskCreatePinnedToCore(
    Send_power
    ,  "Send_power"   // A name just for humans
    ,  8192  // This stack size can be checked & adjusted by reading the Stack Highwater
    ,  NULL
    ,  2  // Priority of 3 (configMAX_PRIORITIES - 1) being the highest, and 0 being the lowest.
    ,  &Sp 
    ,  0);

  // Now the task scheduler, which takes over control of scheduling individual tasks, is automatically started.
}

void loop()
{
}


double multiple_adc_read(int pinnum){
   // function takes ~ 40 usec for 4 ADC reads
   const int num_samples = 4;
   double reading_sum = 0.0;
   double reading_avg;
   for(int i = 0; i <num_samples ; i++) reading_sum += double(analogRead(pinnum));
   reading_avg = reading_sum/double(num_samples);
   return reading_avg;
}

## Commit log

2020-05-23 Added PCB design
    [ESP32 Wroom energy meter-B_Cu.gbr, ESP32 Wroom energy meter-B_Mask.gbr, ESP32 Wroom energy meter-B_SilkS.gbr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]
2020-11-20 Initial Release
    [Energy monitor Current.xls]
2020-11-21 Some minor updates
    [Energy monitor Current.xls]
